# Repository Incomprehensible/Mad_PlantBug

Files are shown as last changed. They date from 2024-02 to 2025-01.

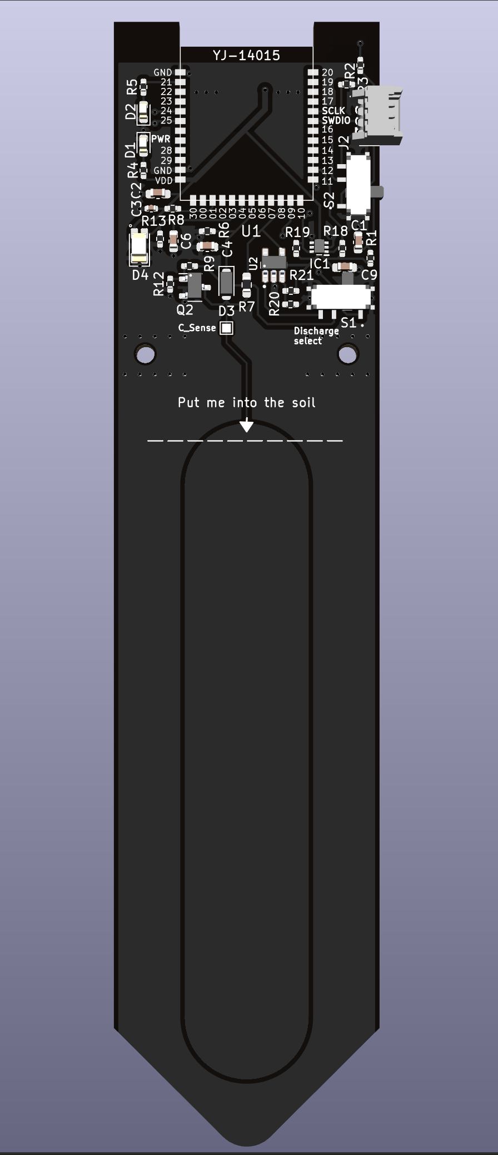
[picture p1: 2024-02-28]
pictures/3d_front.png

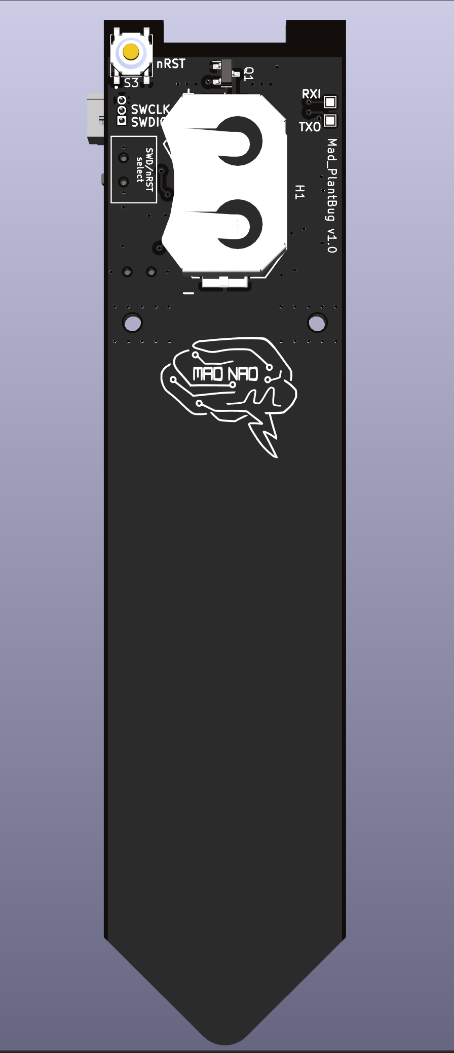
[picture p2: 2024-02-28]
pictures/3d_back.png

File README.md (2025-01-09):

# Mad_PlantBug

Low-power capacitive soil moisture sensor with BLE connectivity.

## Features

* powered via CR2032 coin battery
* transmits telemetry via BLE
* measures ambient light and temperature
* visual indication via LED

Top             |  Bottom
:-------------------------:|:-------------------------:
  |  

## How it works

This sensor determines the amount of soil moisture by measuring changes in capacitance of the probe submerged in soil.\
Insertable part forms a parasitic coplanar capacitor which uses soil as a dielectric medium.\
As the environment around the capacitor changes depending on whether the soil becomes wetter or drier, so does it capacitance.\
Together with a resistance the probe forms an RC low-pass filter.\
Changes in capacitance shape the output waveform observed by the sensor.
\
Measurement pipeline logic is as follows:\
`environment changes -> capacitance changes -> cutoff frequency changes -> peak amplitude changes`

## Capacitance measurement
* Clean PCB measurement in air: ~59pF
* Fully submerged in water: 2nF
<details><summary>Assembly & measurements</summary>
<p>
Powered on
Submerged in water
</p>
</details>

## Current issues
* CR2032 footprint and power pins connection is incorrect.

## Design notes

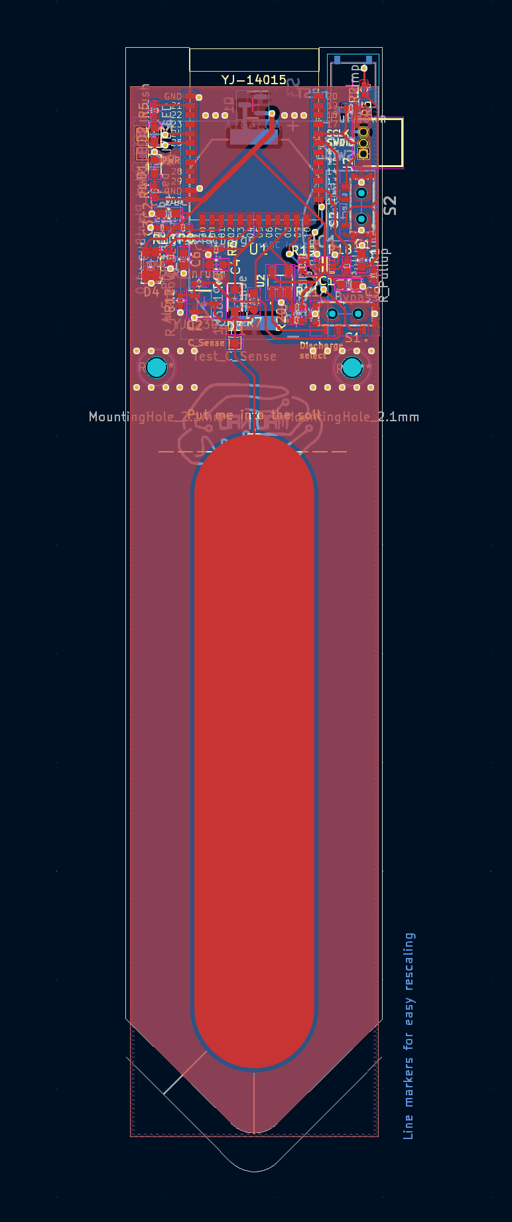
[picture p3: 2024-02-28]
pictures/trace_fcu.png

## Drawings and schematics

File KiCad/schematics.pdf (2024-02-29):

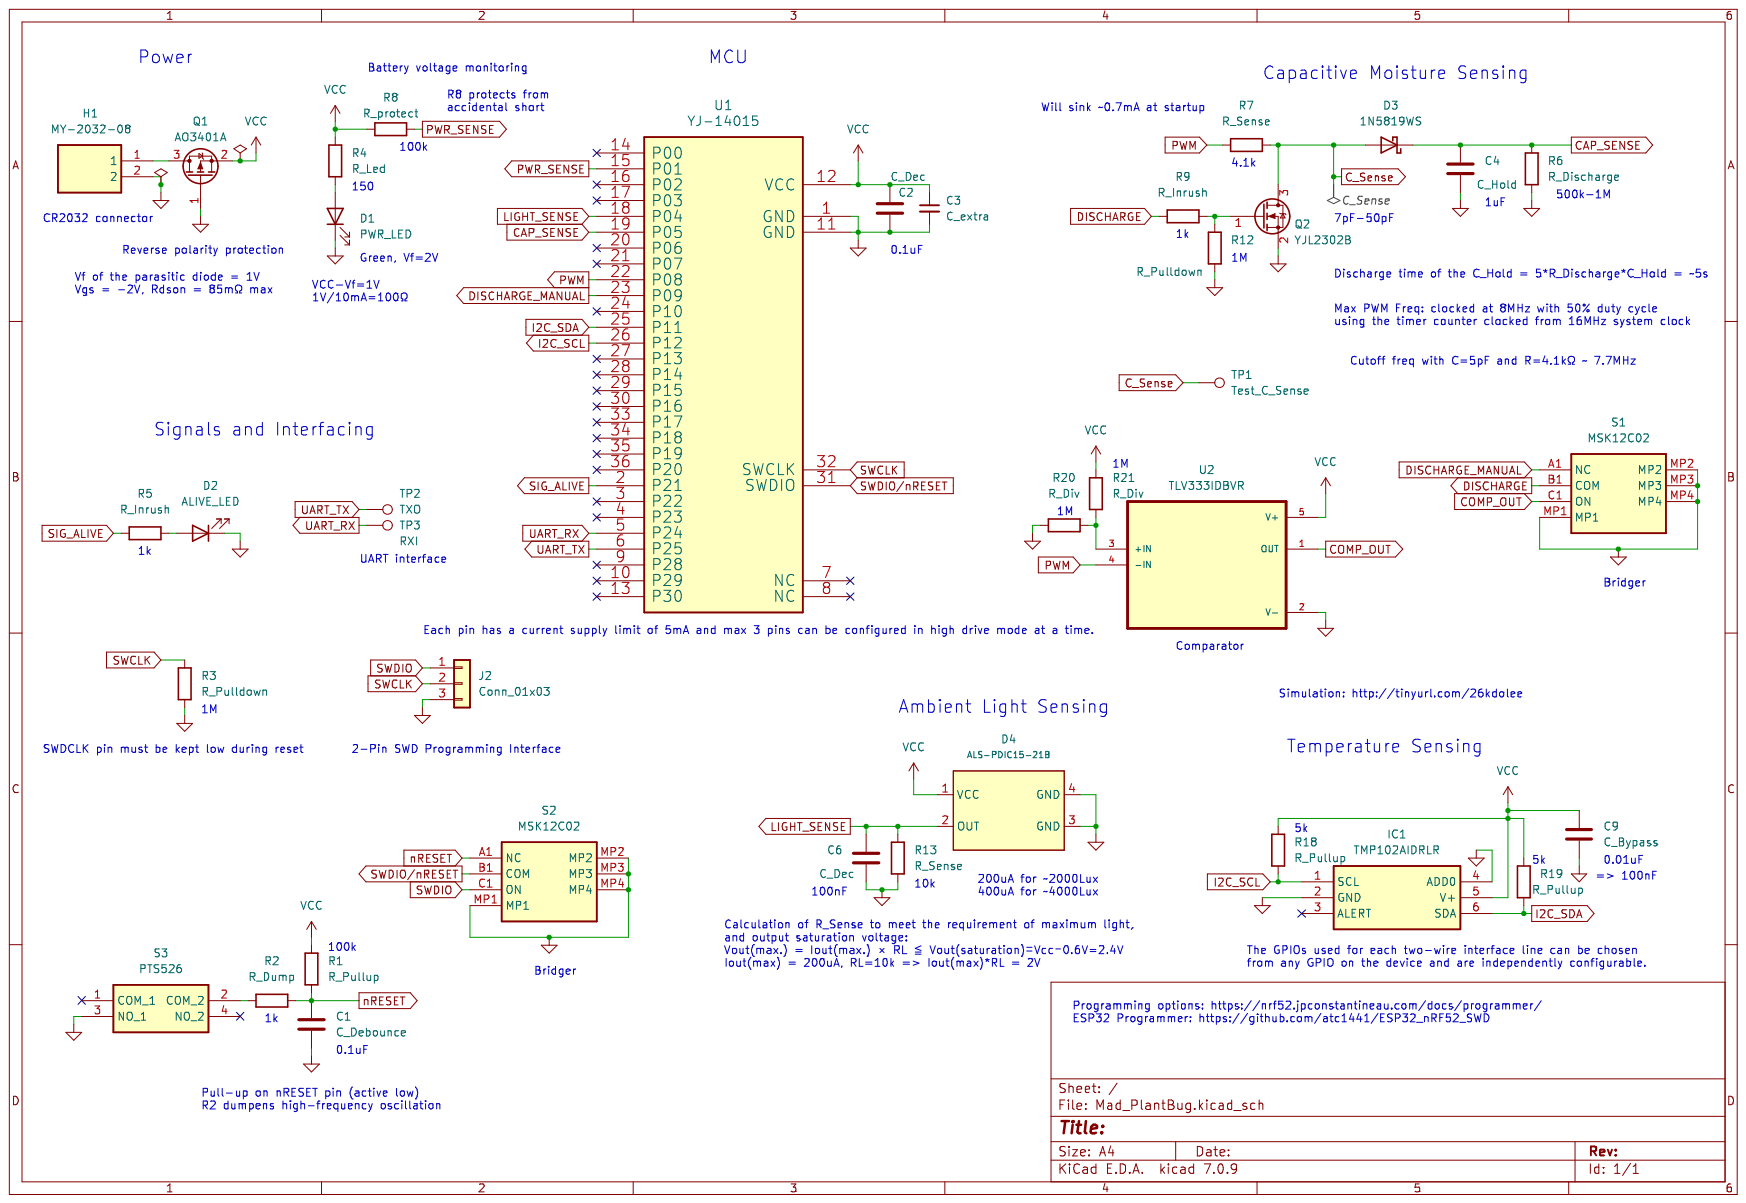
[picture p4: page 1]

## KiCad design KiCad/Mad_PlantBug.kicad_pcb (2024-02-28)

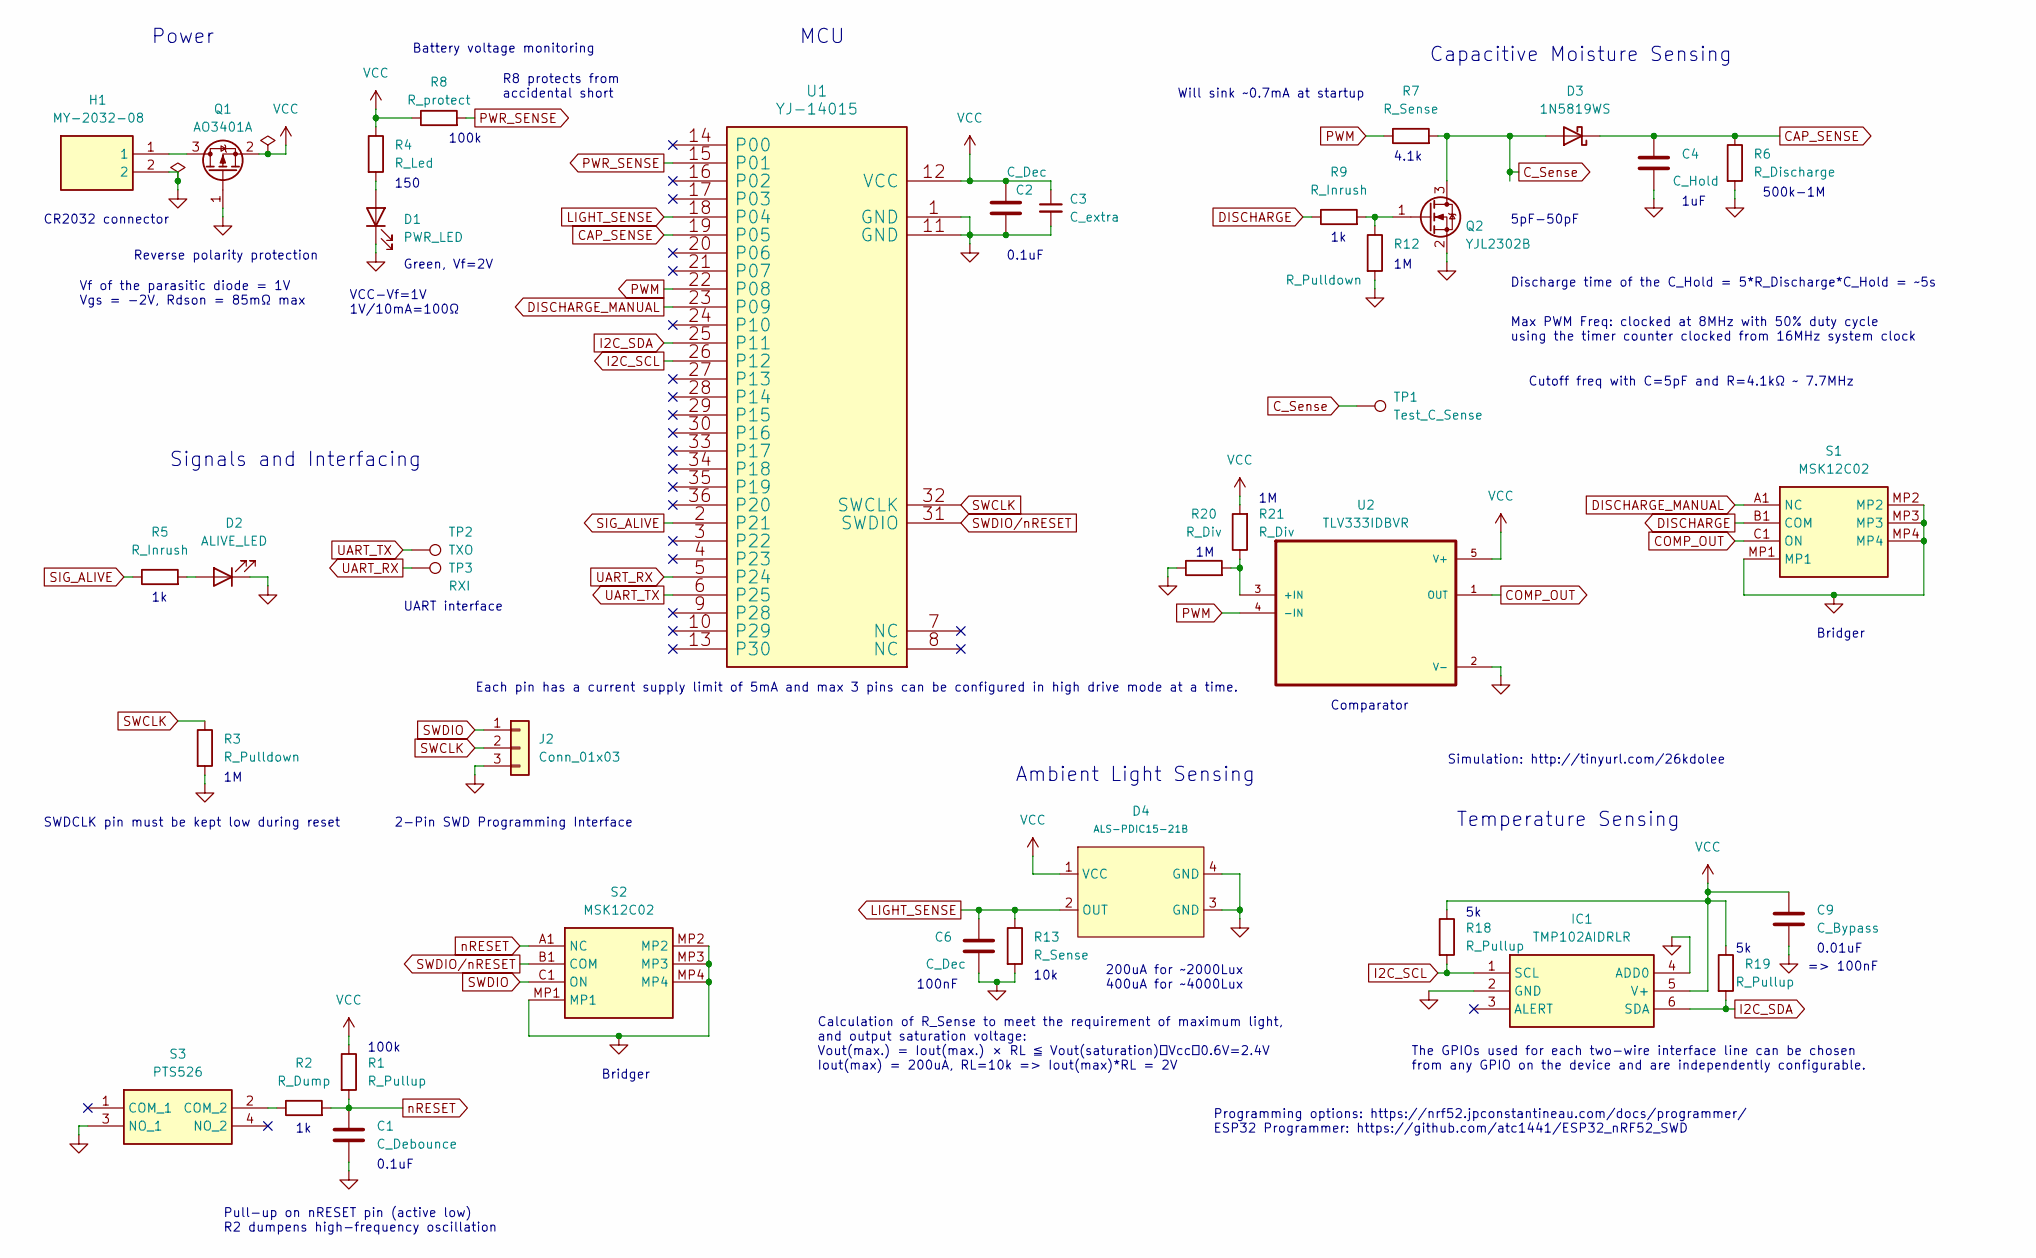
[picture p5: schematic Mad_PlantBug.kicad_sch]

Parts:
C1: C_Debounce; C_0603_1608Metric
C2: C_Dec; C_0603_1608Metric_Pad1.08x0.95mm_HandSolder
C3: C_extra; C_0402_1005Metric
C4: C_Hold; C_0603_1608Metric
C6: C_Dec; C_0603_1608Metric
C9: C_Bypass; C_0603_1608Metric_Pad1.08x0.95mm_HandSolder
D1: PWR_LED; LED_0603_1608Metric
D2: ALIVE_LED; LED_0603_1608Metric
D3: 1N5819WS; D_SOD-323_HandSoldering
D4: ALS-PDIC15-21B; ALS-PDIC15-21BTR8
H1: MY-2032-08; MY203208; Manufacturer_Part_Number MY-2032-08
IC1: TMP102AIDRLR; SOTFL50P160X60-6N; Manufacturer_Part_Number TMP102AIDRLR; Mouser Part Number 595-TMP102AIDRLR
J2: Conn_01x03; MOLEX_530480310
Q1: AO3401A; SOT-23
Q2: YJL2302B; SOT-23-3
R1, R18, R19: R_Pullup; R_0402_1005Metric_Pad0.72x0.64mm_HandSolder
R2: R_Dump; R_0402_1005Metric_Pad0.72x0.64mm_HandSolder
R3, R12: R_Pulldown; R_0402_1005Metric_Pad0.72x0.64mm_HandSolder
R4: R_Led; R_0402_1005Metric_Pad0.72x0.64mm_HandSolder
R5, R9: R_Inrush; R_0402_1005Metric_Pad0.72x0.64mm_HandSolder
R6: R_Discharge; R_0402_1005Metric_Pad0.72x0.64mm_HandSolder
R7: R_Sense; R_0603_1608Metric_Pad0.98x0.95mm_HandSolder
R8: R_protect; R_0402_1005Metric_Pad0.72x0.64mm_HandSolder
R13: R_Sense; R_0402_1005Metric_Pad0.72x0.64mm_HandSolder
R20, R21: R_Div; R_0402_1005Metric_Pad0.72x0.64mm_HandSolder
S1, S2: MSK12C02; Manufacturer_Part_Number MSK12C02
S3: PTS526; PTS526SK15SMTR2LFS; Manufacturer_Part_Number PTS526 SK15 SMTR2 LFS; Mouser Part Number 611-PTS526SK15SMR2L
TP1: Test_C_Sense; TestPoint_Pad_1.0x1.0mm
TP2: TXO; TestPoint_Pad_1.0x1.0mm
TP3: RXI; TestPoint_Pad_1.0x1.0mm
U1: YJ-14015; YJ-14015-Module
U2: TLV333IDBVR; TLV333-SOT95P280X145-5N

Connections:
CAP_SENSE: C4.1, D3.1 (K), R6.1, U1.19 (P05)
COMP_OUT: S1.C1 (ON), U2.1 (OUT)
C_Sense: D3.2 (A), Q2.3 (D), R7.2, TP1.1
DISCHARGE: R9.1, S1.B1 (COM)
DISCHARGE_MANUAL: S1.A1 (NC), U1.23 (P09)
GND: C1.2, C2.2, C3.2, C4.2, C6.2, C9.2, D1.1 (K), D2.1 (K), D4.3 (GND), D4.4 (GND), H1.2, IC1.2 (GND), IC1.4 (ADD0), J2.3, Q1.1 (G), Q2.2 (S), R3.2, R6.2, R12.2, R13.2, R20.1, S1.MP1, S1.MP2, S1.MP3, S1.MP4, S2.MP1, S2.MP2, S2.MP3, S2.MP4, S3.3 (NO_1), U1.1 (GND), U1.11 (GND), U2.2 (V-)
I2C_SCL: IC1.1 (SCL), R18.2, U1.26 (P12)
I2C_SDA: IC1.6 (SDA), R19.2, U1.25 (P11)
LIGHT_SENSE: C6.1, D4.2 (OUT), R13.1, U1.18 (P04)
unnamed: D1.2 (A), R4.2
unnamed: D2.2 (A), R5.2
unnamed: H1.1, Q1.3 (D)
unnamed: Q2.1 (G), R9.2, R12.1
unnamed: R2.1, S3.2 (COM_2)
unnamed: R20.2, R21.1, U2.3 (+IN)
PWM: R7.1, U1.22 (P08), U2.4 (-IN)
PWR_SENSE: R8.2, U1.15 (P01)
SIG_ALIVE: R5.1, U1.2 (P21)
SWCLK: J2.2, R3.1, U1.32 (SWCLK)
SWDIO: J2.1, S2.C1 (ON)
SWDIO/nRESET: S2.B1 (COM), U1.31 (SWDIO)
UART_RX: TP3.1, U1.5 (P24)
UART_TX: TP2.1, U1.6 (P25)
VCC: C2.1, C3.1, C9.1, D4.1 (VCC), IC1.5 (V+), Q1.2 (S), R1.1, R4.1, R8.1, R18.1, R19.1, R21.2, U1.12 (VCC), U2.5 (V+)
nRESET: C1.1, R1.2, R2.2, S2.A1 (NC)

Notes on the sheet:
Simulation: http://tinyurl.com/26kdolee
MCU
100k
Cutoff freq with C=5pF and R=4.1kΩ ~ 7.7MHz
Bridger
0.1uF
500k-1M
CR2032 connector
SWDCLK pin must be kept low during reset
Battery voltage monitoring
VCC-Vf=1V 1V/10mA=100Ω
Ambient Light Sensing
100nF
Pull-up on nRESET pin (active low) R2 dumpens high-frequency oscillation
Green, Vf=2V
0.01uF
150
4.1k
Discharge time of the C_Hold = 5*R_Discharge*C_Hold = ~5s
Calculation of R_Sense to meet the requirement of maximum light, and output saturation voltage: Vout(max.) = Iout(max.) × RL ≦ Vout(saturation)＝Vcc－0.6V=2.4V Iout(max) = 200uA, RL=10k => Iout(max)*RL = 2V
R8 protects from accidental short
Vf of the parasitic diode = 1V Vgs = -2V, Rdson = 85mΩ max
5pF-50pF
Reverse polarity protection
Power
The GPIOs used for each two-wire interface line can be chosen from any GPIO on the device and are independently configurable.
1uF
Capacitive Moisture Sensing
Temperature Sensing
Will sink ~0.7mA at startup
Max PWM Freq: clocked at 8MHz with 50% duty cycle using the timer counter clocked from 16MHz system clock
10k
Each pin has a current supply limit of 5mA and max 3 pins can be configured in high drive mode at a time.
Comparator
200uA for ~2000Lux 400uA for ~4000Lux
2-Pin SWD Programming Interface
=> 100nF
Signals and Interfacing
Programming options: https://nrf52.jpconstantineau.com/docs/programmer/ ESP32 Programmer: https://github.com/atc1441/ESP32_nRF52_SWD
UART interface

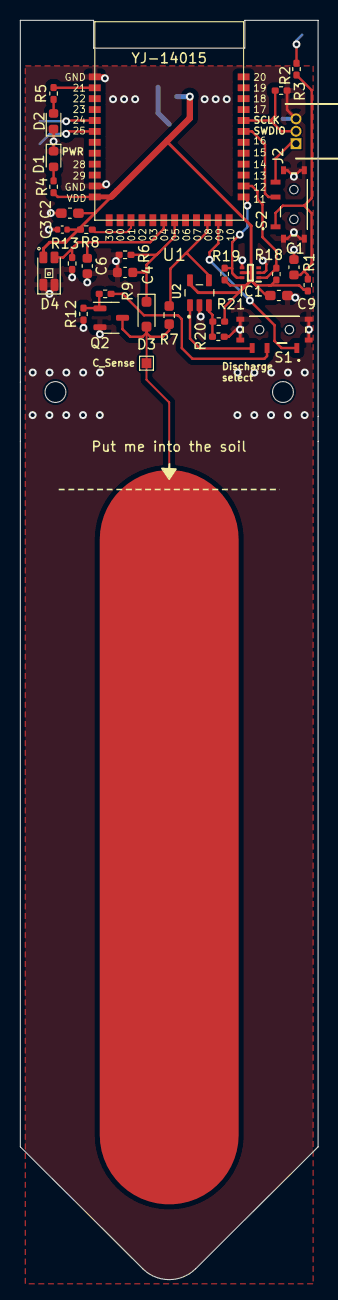
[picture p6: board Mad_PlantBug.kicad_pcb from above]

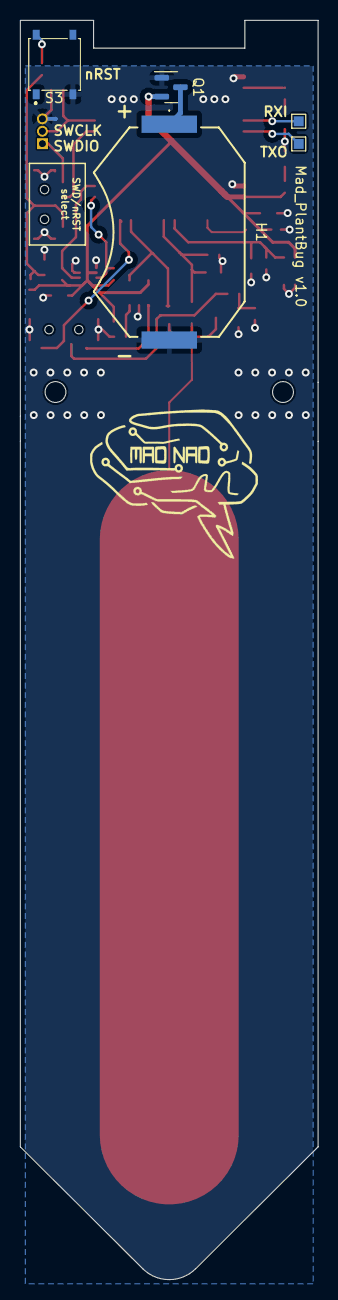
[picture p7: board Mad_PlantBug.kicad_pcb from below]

Board: 2 copper layers, 30.0 x 126.9 mm, 38 parts (5 on the bottom side), 25 nets.

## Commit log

2024-02-17 Added first version of schematics with old symbols for some components.
    [Mad_PlantBug.kicad_pcb, Mad_PlantBug.kicad_sch]
2024-02-22 Last version of the full schematics with all assigned footprints. Added simulaion sheet.
    [Mad_PlantBug.kicad_pcb, Mad_PlantBug.kicad_sch, sim.kicad_sch]
2024-02-25 Finished schematics, layed out the components, added ADC battery voltage input, defined board outline, traced a sensor capacitor.
    [Mad_PlantBug.kicad_pcb, Mad_PlantBug.kicad_sch]
2024-02-28 First version of the sensor is up.
    [Mad_PlantBug.kicad_pcb]
2024-02-28 Added schematics pdf.
2024-02-28 Routed UART, added some designators, added gerbers.
    [Mad_PlantBug-B_Cu.gbl, Mad_PlantBug-B_Mask.gbs, Mad_PlantBug-B_Paste.gbp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]
2024-02-29 Updated schematics pdf.
